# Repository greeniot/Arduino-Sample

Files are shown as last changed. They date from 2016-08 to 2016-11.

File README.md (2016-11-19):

# Arduino-Sample
:car: The car distance sensor using the Arduino with an ultrasonic transducer.

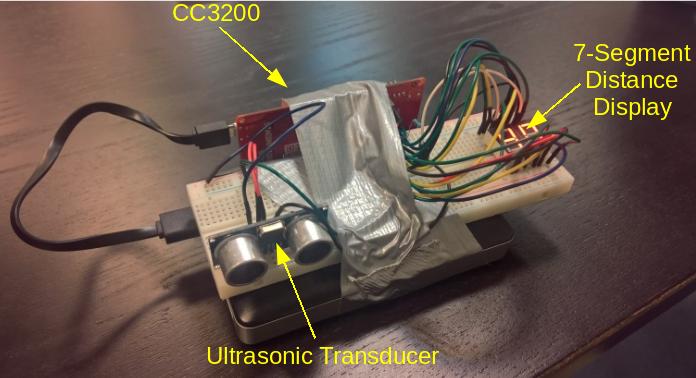
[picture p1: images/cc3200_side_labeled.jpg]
CC3200 with Utrasonic Transducer


* [CC3200 Code](/source/cc3200/distance/distance.ino)
* [Arduino Code](/source/arduino/distance/distance.ino)

# Introduction
In this tutorial you will learn how to built a distance sensor with the Arduino and an ultrasonic transducer.

# Parts
You will need the following parts for this tutorial:
* An ultrasonic transducer,
* two seven-segment displays,
* an Arduino Nano,
* two logic-level n-channel MOSFETs, and
* two 220Ω resistors.

#### Ultrasonic Transducer
The ultrasonic transducer is the main component of the setup. It works exactly the same way like the orientation system of bats. It emits ultrasound which is reflected back by an object. The time between the emission and the reception of the reflection can then be used to calculate the distance to the reflecting object.

The ultrasonic transducer provides four different pins. Two pins for the power supply, GND and VCC, a pin for triggering an ultrasound emission, and a pin which signals when the reflection has been received.

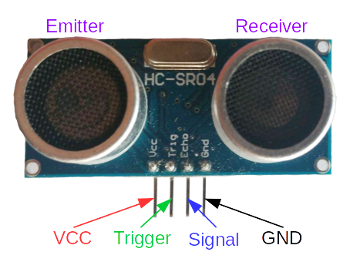
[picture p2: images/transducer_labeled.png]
Utrasonic Transducer


For convenience we are not going to drive the ultrasonic transducer with hand-written code but rather use [this library](https://github.com/JRodrigoTech/Ultrasonic-HC-SR04).

#### Seven-Segment Display
There are several kinds of seven-segment displays. Their main difference is whether they provide a common cathode or anode. The seven-segment displays we are using have a common cathode, that is, all the segments share a common connection to GND. Seven-segment displays provide in addition to the common pin a dedicated pin for each segment. Which pin belongs to which segment is also type-specific. You can look up the assignment in the data-sheet of your display. The segments of a display are labeled with the letters from A to G as in the picture below.

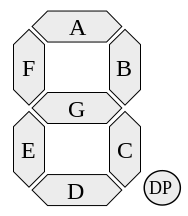
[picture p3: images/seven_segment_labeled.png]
Seven-Segment Display


Since the Arduino Nano does not provide enough pins to drive two seven-segment displays independently we are using two MOSFETs to switch between them with high rate. This allows us to use only one pin for each segment of both displays.

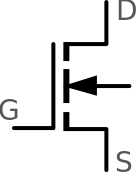
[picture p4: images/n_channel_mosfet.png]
MOSFET-Symbols


Each MOSFET provides three pins, the gate pin (G), the source pin (S), and the drain pin (D). When their is no voltage applied to the gate pin then the MOSFET is in blocking state, that is the resistance between the source and the drain pin is very high such that no current flows between those two pins. When applying a voltage above the threshold voltage of the MOSFET – since we are using logic-level MOSFETs the threshold voltage should be below 5V – the MOSFET becomes conducting. The source and drain pins are now connected with each other and current can flow freely between those two pins.

# Wiring
Let us start with the wiring of all components.

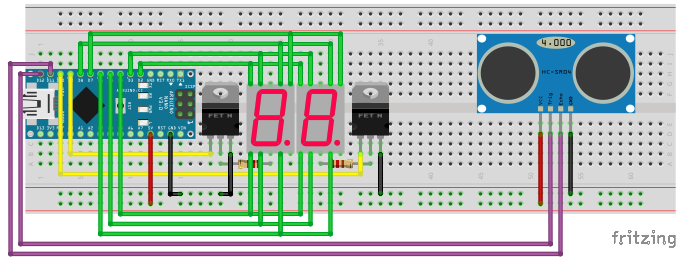
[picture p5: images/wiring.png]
Wiring


First of all the ultrasonic transducer's signal and trigger pins are connected to pin 11 and 12 of the Arduino respectively. Certainly the ultrasonic transducer is also connected to the power supply pins of the Arduino. The common cathode of each seven-segment display is connected via a 220Ω resistor to the particular MOSFET's drain pin. The MOSFET's source pins are connected with GND and the gate pins are connected with pin 9 and 10 of the Arduino. Whereby pin 9 belongs to the MOSFET driving the left display and pin 10 belongs to the MOSFET driving the right display. Further each segment of both displays is connected to one of the pins 2 to 8.

# Software
After successfully wiring all the components the only thing missing is the software. Software for the Arduino is written in a dialect of C++ using the Arduino integrated development environment.

## IDE
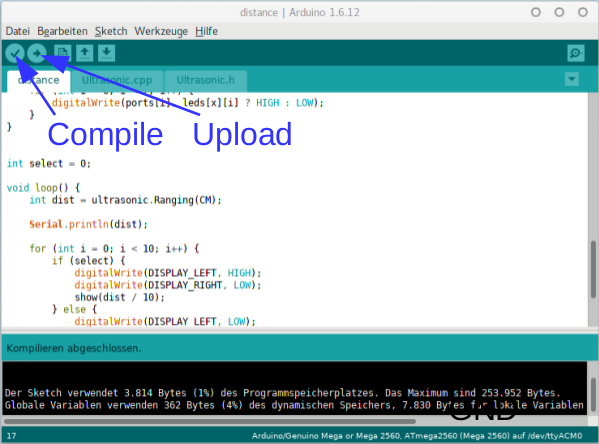
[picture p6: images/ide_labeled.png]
IDE


Besides the main source code view the IDE provides a button to compile the source file and to upload it to the Arduino connected via USB with the computer.

## Source-Code
We already almost done! In the remainder of this tutorial I will explain the source code which is necessary to display the measured distance in centimeters on the two displays.

First of all we need to include the header file of the ultrasonic transducer library. 
```c++
#include "Ultrasonic.h"
```
For convenience we define readable names for the pin numbers using the pre-processor.
```c++
#define TRIGGER         12
#define ECHO            11

#define DISPLAY_A       8
#define DISPLAY_B       7
#define DISPLAY_C       6
#define DISPLAY_D       5
#define DISPLAY_E       4
#define DISPLAY_F       3
#define DISPLAY_G       2

#define DISPLAY_LEFT    9
#define DISPLAY_RIGHT   10
```
We further define an array which contains the pin numbers in alphabetical order of the segment letters they are connected to.
```c++
int ports[7] = {DISPLAY_A, DISPLAY_B, DISPLAY_C, DISPLAY_D,
                DISPLAY_E, DISPLAY_F, DISPLAY_G};
```
To translate a digit to a specific pattern of enabled segments we use yet another array.
```c++
int leds[10][7] = {{1, 1, 1, 1, 1, 1, 0},
                   {0, 1, 1, 0, 0, 0, 0},
                   {1, 1, 0, 1, 1, 0, 1},
                   {1, 1, 1, 1, 0, 0, 1},
                   {0, 1, 1, 0, 0, 1, 1},
                   {1, 0, 1, 1, 0, 1, 1},
                   {1, 0, 1, 1, 1, 1, 1},
                   {1, 1, 1, 0, 0, 0, 0},
                   {1, 1, 1, 1, 1, 1, 1},
                   {1, 1, 1, 1, 0, 1, 1}};
```
For example the digit 0 is translated to `{1, 1, 1, 1, 1, 1, 0}` whereby each position states whether the corresponding segment of the display should be enabled or disabled. The function `show(int x)` displays the digit `x` on the display. Therefore it iterates over all segments, looks up the pin number of each segment and enables the segment depending on the corresponding pattern.
```c++
void show(int x) {
    for (int i = 0; i < 7; i++) {
        digitalWrite(ports[i], leds[x][i] ? HIGH : LOW);
    }
}
```
What is still missing is the `setup()` function. The setup function sets the mode of all the pins we are using to `OUTPUT` and initializes the serial connection to the computer which is useful for debugging purposes.
```c++
void setup() {
    for (int i = 0; i < 7; i++) {
        pinMode(ports[i], OUTPUT);
    }

    pinMode(DISPLAY_LEFT, OUTPUT);
    pinMode(DISPLAY_RIGHT, OUTPUT);

    Serial.begin(9600);
}
```
Moreover we need to initialize the ultrasonic transducer using the library.
```c++
Ultrasonic ultrasonic(TRIGGER, ECHO);
```
Finally we need to write the `loop()` function. The loop function is executed in an infinite loop which consists of measuring the distance and then displaying it on the displays. To display the distance we switch between the two displays using the MOSFETs with a rate of 10ms. We display the most significant digit of the distance on the left and the least significant digit on the right display. This way both displays together show the distance measured in centimeters in the decimal system.
```c++
int select = 0;

void loop() {
    // request the distance in centimeters using the library
    int dist = ultrasonic.Ranging(CM);
    
    // print the distance for debugging purposes
    Serial.println(dist);

    for (int i = 0; i < 10; i++) {
        if (select) {
            // enable the left display
            digitalWrite(DISPLAY_LEFT, HIGH);
            digitalWrite(DISPLAY_RIGHT, LOW);
            // show the most significant digit
            show(dist / 10);
        } else {
            // enable the right display
            digitalWrite(DISPLAY_LEFT, LOW);
            digitalWrite(DISPLAY_RIGHT, HIGH);
            // show the least significant digit
            show(dist % 10);
        }
        // switch to the other display and sleep for 10ms
        select = !select;
        delay(10);
    }
}
```

---

#### Licenses
* [Seven-Segment Display](https://commons.wikimedia.org/wiki/File:Seven_segment_05_Pengo.jpg): CC BY-SA 3.0
* [MOSFET-Symbols](https://commons.wikimedia.org/wiki/File:MISFET-Transistor_Symbole.svg): CC BY-SA 3.0
* [Seven-Segment Labeled](https://commons.wikimedia.org/wiki/File:7_segment_display_labeled.svg): CC BY-SA 3.0

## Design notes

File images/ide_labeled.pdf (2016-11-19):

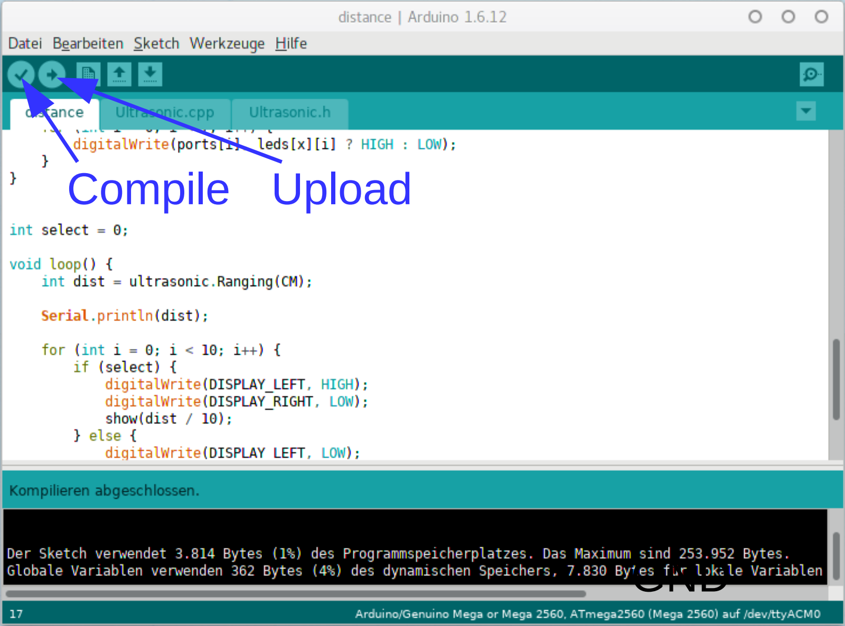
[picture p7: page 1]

Compile

GND

Upload

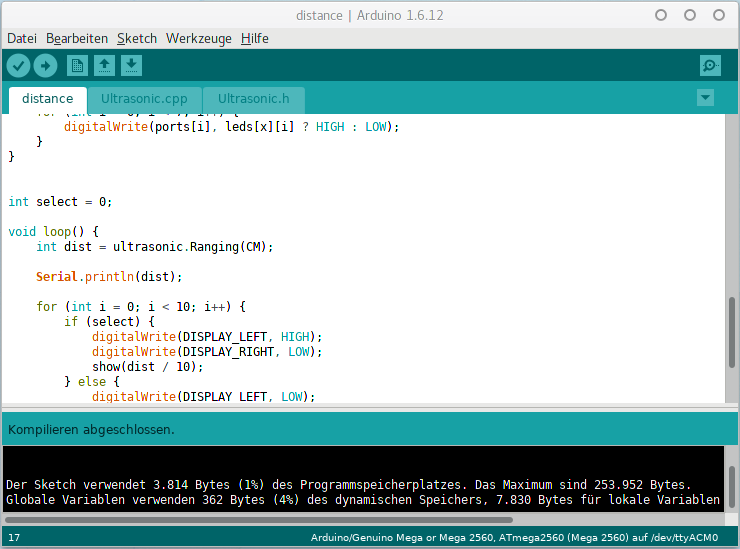
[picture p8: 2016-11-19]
images/ide_raw.png

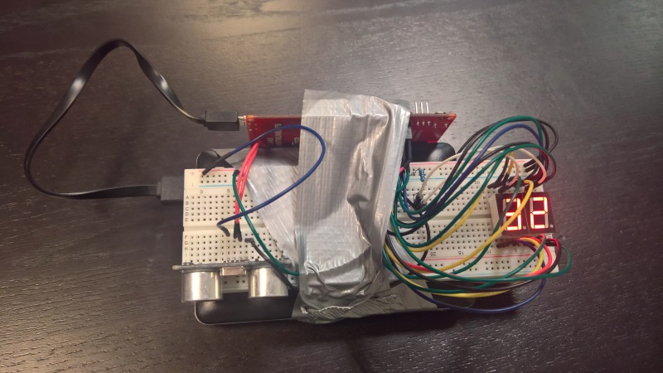
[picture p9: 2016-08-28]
images/cc3200_top.jpg

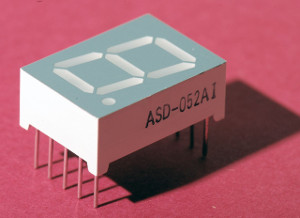
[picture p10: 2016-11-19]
images/seven_segment.jpg

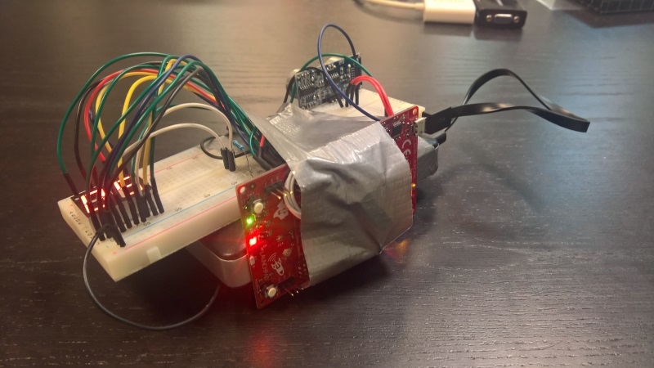
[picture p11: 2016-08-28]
images/cc3200_back.jpg

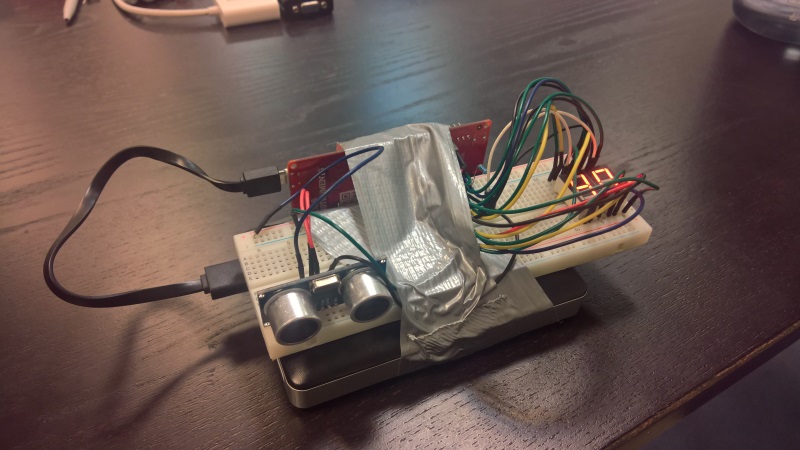
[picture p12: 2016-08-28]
images/cc3200_side.jpg

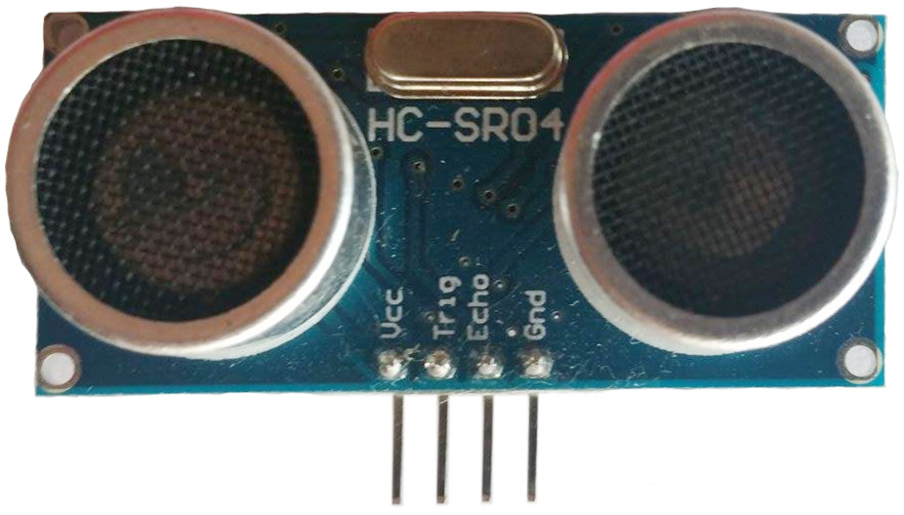
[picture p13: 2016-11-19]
images/transducer_raw.png

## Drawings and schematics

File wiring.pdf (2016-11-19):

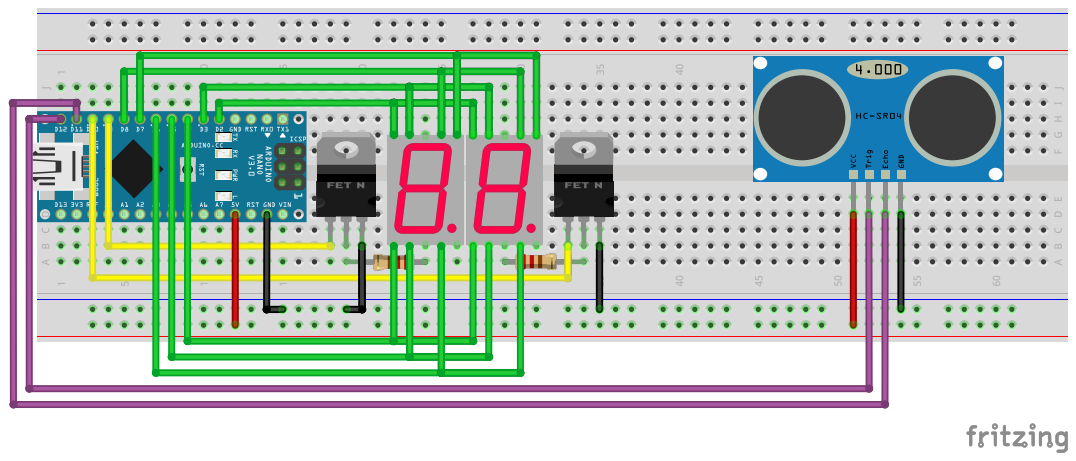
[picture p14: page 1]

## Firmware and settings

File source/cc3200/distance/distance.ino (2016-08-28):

#include <Energia.h>
#include <WiFi.h>
#include "wifi.h"
#include "http.h"
#include "Ultrasonic.h"

#define WLAN_PUB_SSID   "INSERT_HERE"
#define WLAN_KEY_CODE   ""
#define RPI_IP_ADDRESS  "192.168.10.35"
#define RPI_PORT        80
#define RPI_PATH        "/distance"
#define TRIGGER         15
#define ECHO            14

Ultrasonic ultrasonic(TRIGGER, ECHO);

int ports[2][7] = {{ 30, 24, 10, 2, 27, 28, 29 },
                   {  3,  4,  5, 6,  7,  8,  9 }};

int leds [10][7] = {{ 1, 1, 1, 1, 1, 1, 0 },
                    { 0, 1, 1, 0, 0, 0, 0 },
                    { 1, 1, 0, 1, 1, 0, 1 },
                    { 1, 1, 1, 1, 0, 0, 1 },
                    { 0, 1, 1, 0, 0, 1, 1 },
                    { 1, 0, 1, 1, 0, 1, 1 },
                    { 1, 0, 1, 1, 1, 1, 1 },
                    { 1, 1, 1, 0, 0, 0, 0 },
                    { 1, 1, 1, 1, 1, 1, 1 },
                    { 1, 1, 1, 1, 0, 1, 1 }};

void showDigit(int x, int num) {
  for (int i = 0; i < 7; i++) {
    digitalWrite(ports[num][i], leds[x][i] ? HIGH : LOW);
  }
}

void show(int dist) {
  showDigit((dist / 10) % 10, 0);
  showDigit((dist % 10), 1);
}

void setup() {
  Serial.begin(9600);

  for (int i = 0; i < 7; i++) {
    pinMode(ports[0][i], OUTPUT);
    pinMode(ports[1][i], OUTPUT);
  } 

  connectWifi(WLAN_PUB_SSID, WLAN_KEY_CODE);
}

void loop() {
  char receive_msg_buffer[1024];
  char send_msg_buffer[128];
  
  while (true) {
    delay(100);
    float distance = ultrasonic.Ranging(CM);

    if (distance > 49) {
      distance = 50.0;
    }

    show((int)distance);
    Serial.println(distance);
    sprintf(send_msg_buffer, "%lf", distance);
    httpPostRequest(RPI_IP_ADDRESS, RPI_PORT, RPI_PATH, send_msg_buffer, receive_msg_buffer);
  }
}

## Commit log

2016-09-06 [arduino] add source code
2016-09-06 [arduino] reformat code
2016-11-19 add MOSFET symbols
2016-11-19 add wiring images
    [wiring.fzz]
2016-11-19 update images
    [wiring.fzz]
